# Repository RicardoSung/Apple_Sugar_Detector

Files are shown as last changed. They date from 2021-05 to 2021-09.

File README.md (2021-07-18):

# Apple Sugar Detector
> Apple sugar detector is a complete set of the construction of DIYed brix hydrometer targeted on Apples.

## Installation

* Prerequisites:
   *  Autodesk Inventor 2020 +
   *  Cadence OrCAD Alllegro 17.4 +
   *  Xilinx ISE Designer 14.7 +
   *  Python 3.8 
   *  Tensorflow 2.5.0   
   *  [usb-serial-for-android](https://github.com/mik3y/usb-serial-for-android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,are%20required%3B%20all%20drivers%20are%20implemented%20in%20Java.) library

For installable APK, please direct to `release`.

## Usage example

TBD

## Release History

### 0.x Internal Version

* 0.0.1
    * Work in progress, framework uploaded
* 0.1
    * PCB design first version uploaded
    * External structure first version uploaded
    * Android application first version uploaded
* 0.2
    * PCB design second version uploaded
    * External structure second version uploaded
    * Android application second version uploaded
    * Optic simulation first version uploaded
* 0.3
    * Neural network first version uploaded
    * External structure third version uploaded
    * Optic simulation second version uploaded
* 0.4
    * Optic simulation third version uploaded
    * 3D printing first version
* 0.5
    * Optic simulation fourth version uploaded
    * 3D printing second version
    * First training dataset acquired 

## Meta

Distributed under the GPL license. See ``LICENSE`` for more information.

## Contributing

1. Fork it (<https://github.com/GeekerRicardo/fruit_companion/fork>)
2. Create your feature branch (`git checkout -b feature/fooBar`)
3. Commit your changes (`git commit -am 'Add some fooBar'`)
4. Push to the branch (`git push origin feature/fooBar`)
5. Create a new Pull Request

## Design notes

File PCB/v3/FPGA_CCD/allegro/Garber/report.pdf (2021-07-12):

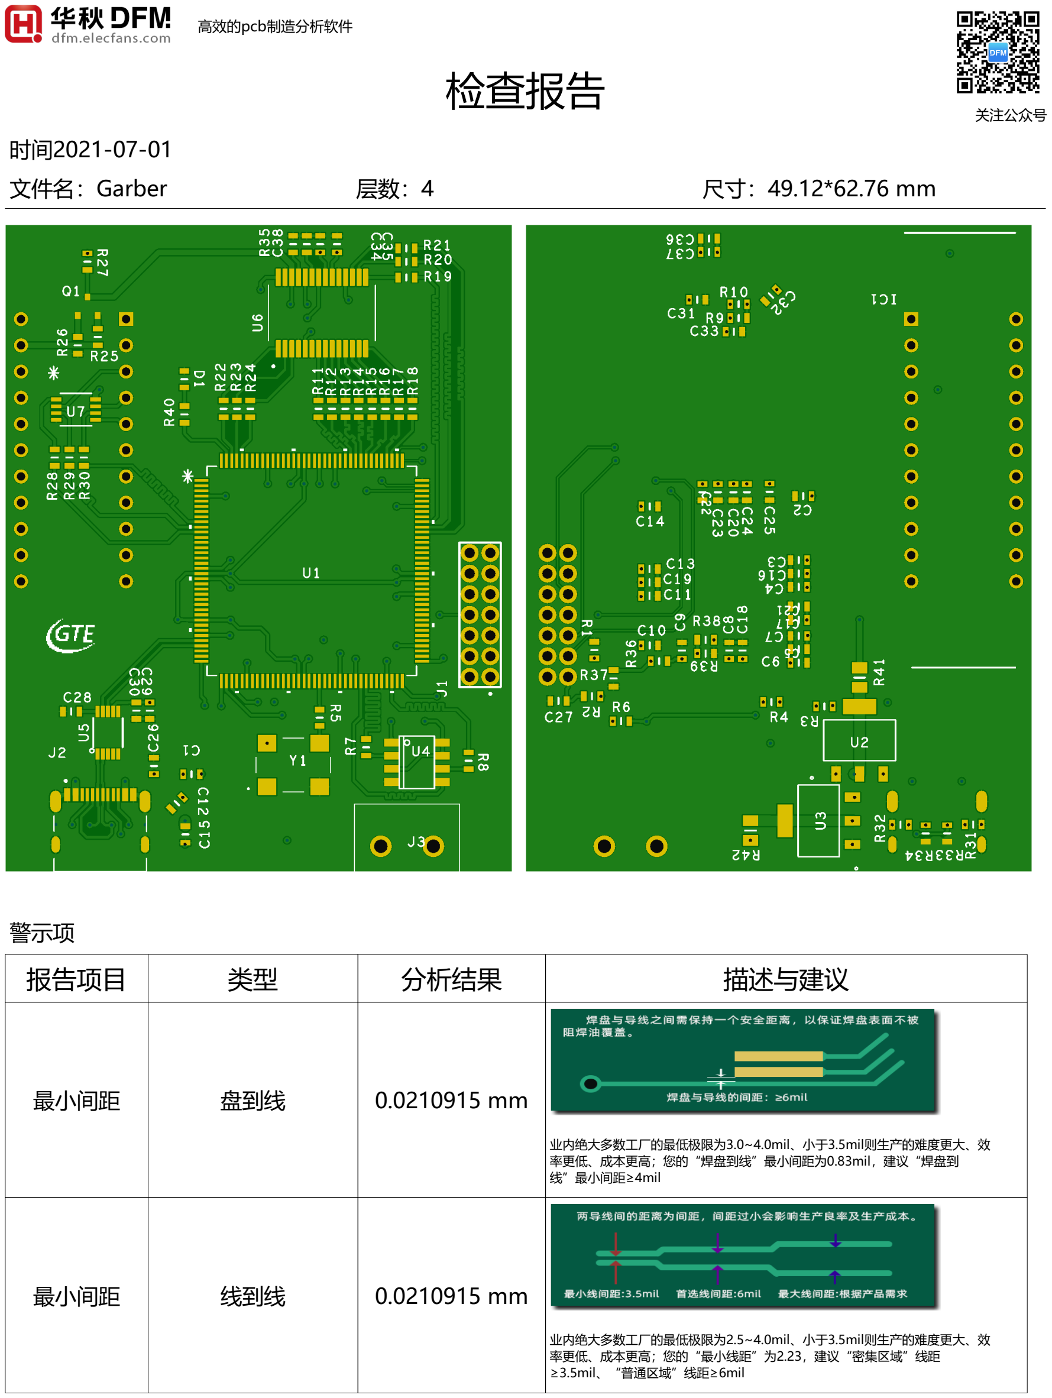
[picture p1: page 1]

高效的pcb制造分析软件

检查报告 | 关注公众号

时间2021-07-01

文件名：Garber | 层数：4 | 尺寸：49.12*62.76 mm

警示项
报告项目 | 类型 | 分析结果 | 描述与建议
最小间距 | 盘到线 | 0.0210915 mm | 业内绝大多数工厂的最低极限为3.0~4.0mil、小于3.5mil则生产的难度更大、效 率更低、成本更高；您的“焊盘到线”最小间距为0.83mil，建议“焊盘到 线”最小间距≥4mil
最小间距 | 线到线 | 0.0210915 mm | 业内绝大多数工厂的最低极限为2.5~4.0mil、小于3.5mil则生产的难度更大、效 率更低、成本更高；您的“最小线距”为2.23，建议“密集区域”线距 ≥3.5mil、“普通区域”线距≥6mil

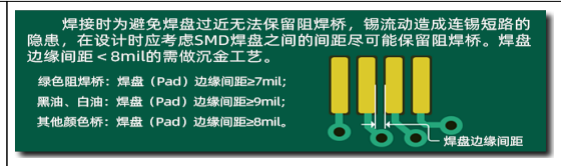
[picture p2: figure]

SMD间距 | 不同网络SMD焊盘间 距 | 0.169926 mm | 您的“SMD焊盘”最小间距为6.69mil会影响生产效率、品质良率，而且存在连 锡隐患，建议“SMD焊盘”最小间距 ≥ 8 mil

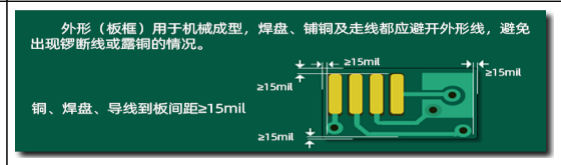
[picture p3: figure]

板边距离 | 铜/PAD/线到板边距 离 | 板边异常 | 业内绝大多数工厂的锣边极限为8mil，小于该极限值，有露铜甚至断线的隐患； 您的“导线/焊盘/覆铜到板边”最小间距为0.00mil，建议≥10mil；如是V割 边，建议≥15mil，具体极限值与板厚、V刀角度有关，规则请查看“DFM文 档”

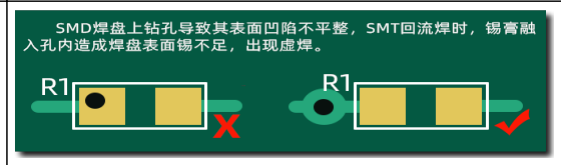
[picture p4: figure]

孔上焊盘 | 插件孔 | 有盘中孔 | 您的“设计”存在“孔在SMD焊盘上”，会影响焊盘的平整度，可能会导致焊 锡不良。

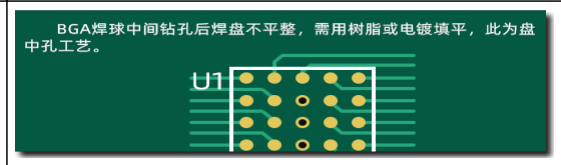
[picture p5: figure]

孔上焊盘 | 盘中孔 | 有盘中孔 | 您的“设计”可能存在“盘中孔”，如是BGA区域，须用树脂塞孔工艺，会导致 额外收费。

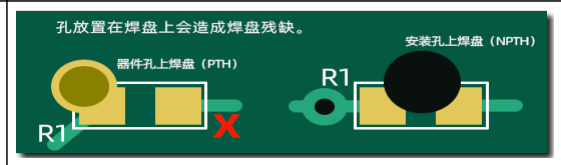
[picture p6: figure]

孔上焊盘 | 过孔上焊盘 | 有盘中孔 | 您的“设计”存在“孔在SMD焊盘上”，会影响焊盘的平整度，可能会导致焊 锡不良。

全部检查项
报告项目 | 类型 | 分析结果
电气信号 开短路 | 断头线 | 正常
| 孤立铜 | 正常
| 无效过孔 | 正常
| 片式SMD没连线路 | 正常
| 锐角 | 正常
最小线宽 | 最小线宽 | 正常 0.127 mm

最小间距 | 线到线 | 30pis 0.0210915 mm
| 盘到线 | 241pis 0.0210915 mm
| 盘到盘 | 正常 0.0210915 mm
最小焊盘 | BGA焊盘 | 正常
| 常规焊盘 | 正常
| 长条焊盘 | 正常
SMD间距 | 同网络SMD焊盘间距 | 正常
| 不同网络SMD焊盘间 距 | 175pis 0.169926 mm
| 同器件焊盘间距 | 正常
| 不同器件焊盘间距 | 正常
网格铺铜 | 网格线宽 | 正常
| 网格线距 | 正常
孔大小 | 最小孔径 | 正常 0.3302 mm
| 最大孔径 | 正常
| 厚径比 | 正常
槽孔 | 最小槽宽 | 正常
| 最大槽宽 | 正常
| 槽长宽比 | 正常
孔环 | 过孔孔环 | 正常
| 插件孔孔环 | 正常
孔到孔 | 同网络过孔 | 正常
| 不同网络过孔 | 正常
| 插件孔 | 1pis 有盘中孔

孔到线 | 过孔到表层 | 正常 0.2667 mm
| 插件孔到表层 | 正常 0.2667 mm
| 过孔到内层 | 正常
| 插件孔到内层 | 正常
| NPTH到铜 | 正常 0.2667 mm
板边距离 | 铜/PAD/线到板边距 离 | 16pis 板边异常
| SMD到板边距离 | 正常
| 孔到板边 | 正常
特殊孔 | 半孔 | 正常
| 盲埋孔 | 正常
| 盲埋孔距离 | 正常
| 激光孔 | 正常
| 正/长方形孔 | 正常
焊盘规格 | 焊盘大小异常 | 正常
| 分装内间距异常 | 正常
孔上焊盘 | 盘中孔 | 21pis 有盘中孔
| 插件孔 | 1pis 有盘中孔
| 过孔上焊盘 | 59pis 有盘中孔
| 非金属孔 | 正常
阻焊开窗 | 阻焊异常 | 正常
| 阻焊盖线 | 正常
| 阻焊间隙 | 正常
| 同网络阻焊间隙 | 正常
| 漏阻焊桥 | 正常
| 同网络漏阻焊桥 | 正常

孔密度 | 孔密度 | 正常
沉金面积 | 沉金面积 | 正常
飞针点数 | 飞针点数 | 正常

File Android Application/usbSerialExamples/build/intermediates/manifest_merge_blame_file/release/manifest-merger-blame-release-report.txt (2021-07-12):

1<?xml version="1.0" encoding="utf-8"?>
2<manifest xmlns:android="http://schemas.android.com/apk/res/android"
3    package="com.hoho.android.usbserial.examples" >
4
5    <uses-sdk
6        android:minSdkVersion="24"
6-->D:\Android\AndroidCode\usb-serial-for-android-master\usbSerialExamples\src\main\AndroidManifest.xml
7        android:targetSdkVersion="30" />
7-->D:\Android\AndroidCode\usb-serial-for-android-master\usbSerialExamples\src\main\AndroidManifest.xml
8    <!-- mipmap/ic_launcher created with Android Studio -> New -> Image Asset using @color/colorPrimary and USB clip art -->
9    <application
9-->D:\Android\AndroidCode\usb-serial-for-android-master\usbSerialExamples\src\main\AndroidManifest.xml:7:5-32:19
10        android:appComponentFactory="androidx.core.app.CoreComponentFactory"
10-->[androidx.core:core:1.3.1] C:\Users\Voluntino\.gradle\caches\transforms-3\2d8ae992b7b26928b91c87685f1e70d4\transformed\core-1.3.1\AndroidManifest.xml:24:18-86
11        android:extractNativeLibs="false"
12        android:icon="@mipmap/red_apple"
12-->D:\Android\AndroidCode\usb-serial-for-android-master\usbSerialExamples\src\main\AndroidManifest.xml:8:9-41
13        android:label="@string/app_name"
13-->D:\Android\AndroidCode\usb-serial-for-android-master\usbSerialExamples\src\main\AndroidManifest.xml:9:9-41
14        android:theme="@style/AppTheme" >
14-->D:\Android\AndroidCode\usb-serial-for-android-master\usbSerialExamples\src\main\AndroidManifest.xml:10:9-40
15
16        <!--
17             for this simple app launchMode=singleTask and singleTop have same effect.
18             If you would start another activity in the app, e.g. Android Settings
19             then you should use singleTask, else a new MainActivity would be started
20             when the settings activity is currently shown
21        -->
22        <activity
22-->D:\Android\AndroidCode\usb-serial-for-android-master\usbSerialExamples\src\main\AndroidManifest.xml:16:9-31:20
23            android:name="com.hoho.android.usbserial.examples.MainActivity"
23-->D:\Android\AndroidCode\usb-serial-for-android-master\usbSerialExamples\src\main\AndroidManifest.xml:17:13-41
24            android:label="@string/app_name"
24-->D:\Android\AndroidCode\usb-serial-for-android-master\usbSerialExamples\src\main\AndroidManifest.xml:18:13-45
25            android:launchMode="singleTask"
25-->D:\Android\AndroidCode\usb-serial-for-android-master\usbSerialExamples\src\main\AndroidManifest.xml:19:13-44
26            android:windowSoftInputMode="stateHidden|adjustResize" >
26-->D:\Android\AndroidCode\usb-serial-for-android-master\usbSerialExamples\src\main\AndroidManifest.xml:20:13-67
27            <intent-filter>
27-->D:\Android\AndroidCode\usb-serial-for-android-master\usbSerialExamples\src\main\AndroidManifest.xml:21:13-24:29
28                <action android:name="android.intent.action.MAIN" />
28-->D:\Android\AndroidCode\usb-serial-for-android-master\usbSerialExamples\src\main\AndroidManifest.xml:22:17-69
28-->D:\Android\AndroidCode\usb-serial-for-android-master\usbSerialExamples\src\main\AndroidManifest.xml:22:25-66
29
30                <category android:name="android.intent.category.LAUNCHER" />
30-->D:\Android\AndroidCode\usb-serial-for-android-master\usbSerialExamples\src\main\AndroidManifest.xml:23:17-77
30-->D:\Android\AndroidCode\usb-serial-for-android-master\usbSerialExamples\src\main\AndroidManifest.xml:23:27-74
31            </intent-filter>
32            <intent-filter>
32-->D:\Android\AndroidCode\usb-serial-for-android-master\usbSerialExamples\src\main\AndroidManifest.xml:25:13-27:29
33                <action android:name="android.hardware.usb.action.USB_DEVICE_ATTACHED" />
33-->D:\Android\AndroidCode\usb-serial-for-android-master\usbSerialExamples\src\main\AndroidManifest.xml:26:17-90
33-->D:\Android\AndroidCode\usb-serial-for-android-master\usbSerialExamples\src\main\AndroidManifest.xml:26:25-87
34            </intent-filter>
35
36            <meta-data
36-->D:\Android\AndroidCode\usb-serial-for-android-master\usbSerialExamples\src\main\AndroidManifest.xml:28:13-30:57
37                android:name="android.hardware.usb.action.USB_DEVICE_ATTACHED"
37-->D:\Android\AndroidCode\usb-serial-for-android-master\usbSerialExamples\src\main\AndroidManifest.xml:29:17-79
38                android:resource="@xml/device_filter" />
38-->D:\Android\AndroidCode\usb-serial-for-android-master\usbSerialExamples\src\main\AndroidManifest.xml:30:17-54
39        </activity>
40    </application>
41
42</manifest>

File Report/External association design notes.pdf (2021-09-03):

# 外部附件设计说明

# 学校：电子科技大学（UESTC）

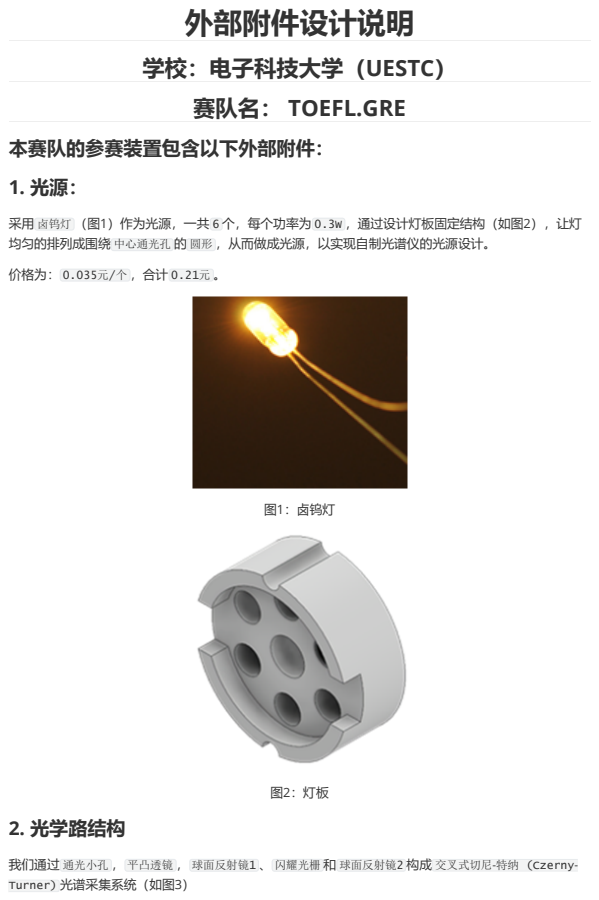
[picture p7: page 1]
本赛队的参赛装置包含以下外部附件：; 价格为： 0.035元/个 ，合计 0.21元 。; 图1：卤钨灯; 2. 光学路结构

赛队名： TOEFL.GRE

采用 卤钨灯 （图1）作为光源，一共 6 个，每个功率为 0.3W ，通过设计灯板固定结构（如图2），让灯
均匀的排列成围绕 中心通光孔 的 圆形 ，从而做成光源，以实现自制光谱仪的光源设计。

我们通过 通光小孔 ， 平凸透镜 ， 球面反射镜1 、 闪耀光栅 和 球面反射镜2 构成 交叉式切尼-特纳 (Czerny-
Turner) 光谱采集系统（如图3）

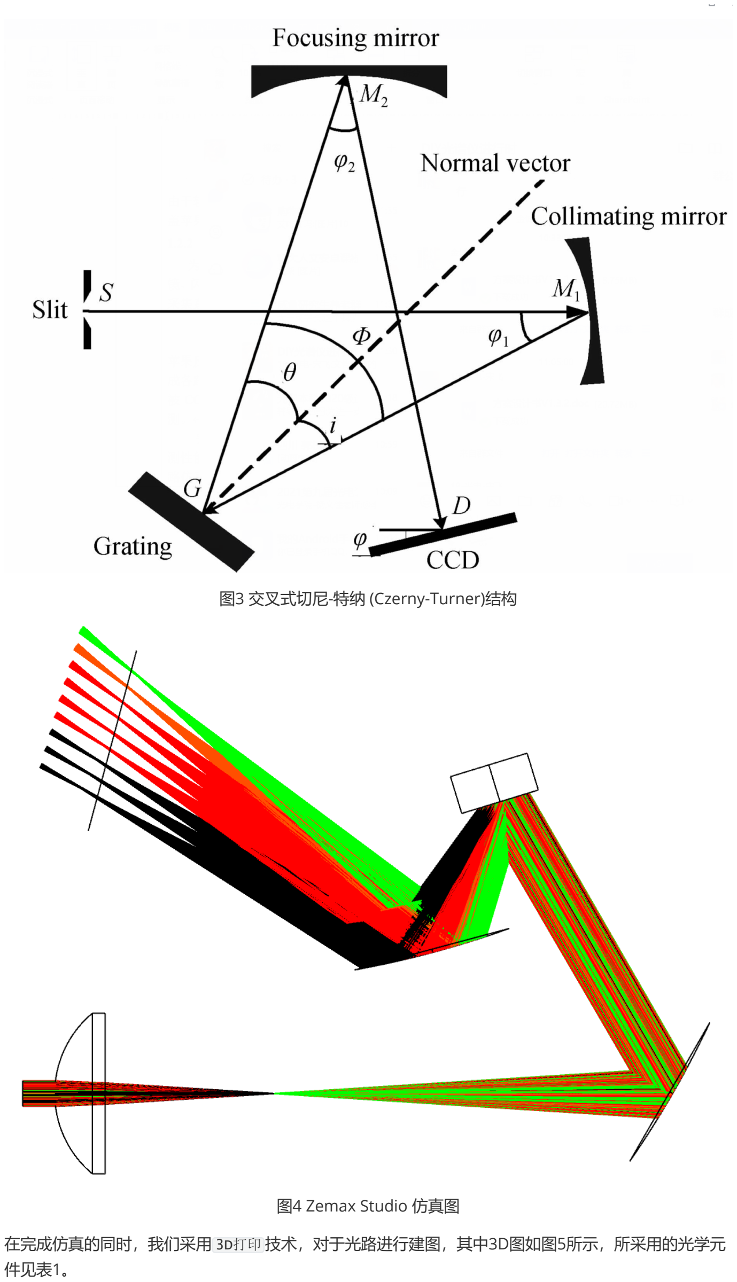
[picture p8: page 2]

图3 交叉式切尼-特纳 (Czerny-Turner)结构

图4 Zemax Studio 仿真图

在完成仿真的同时，我们采用 3D打印 技术，对于光路进行建图，其中3D图如图5所示，所采用的光学元 件见表1。

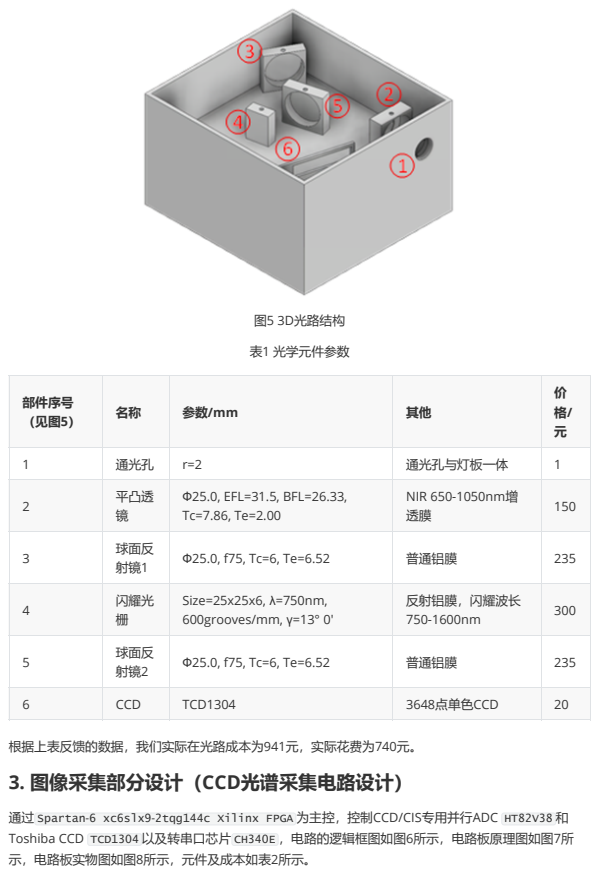
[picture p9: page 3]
图5 3D光路结构; 表1 光学元件参数; 根据上表反馈的数据，我们实际在光路成本为941元，实际花费为740元。 3. 图像采集部分设计（CCD光谱采集电路设计）

部件序号 （见图5） | 名称 | 参数/mm | 其他 | 价 格/ 元

1 | 通光孔 | r=2 | 通光孔与灯板一体 | 1

2 | 平凸透 镜 | Ф25.0, EFL=31.5, BFL=26.33, Tc=7.86, Te=2.00 | NIR 650-1050nm增 透膜 | 150

3 | 球面反 射镜1 | Ф25.0, f75, Tc=6, Te=6.52 | 普通铝膜 | 235

4 | 闪耀光 栅 | Size=25x25x6, λ=750nm, 600grooves/mm, γ=13° 0' | 反射铝膜，闪耀波长 750-1600nm | 300

5 | 球面反 射镜2 | Ф25.0, f75, Tc=6, Te=6.52 | 普通铝膜 | 235

6 | CCD | TCD1304 | 3648点单色CCD | 20

通过 Spartan-6 xc6slx9-2tqg144c Xilinx FPGA 为主控，控制CCD/CIS专用并行ADC HT82V38 和
Toshiba CCD TCD1304 以及转串口芯片 CH340E ，电路的逻辑框图如图6所示，电路板原理图如图7所
示，电路板实物图如图8所示，元件及成本如表2所示。

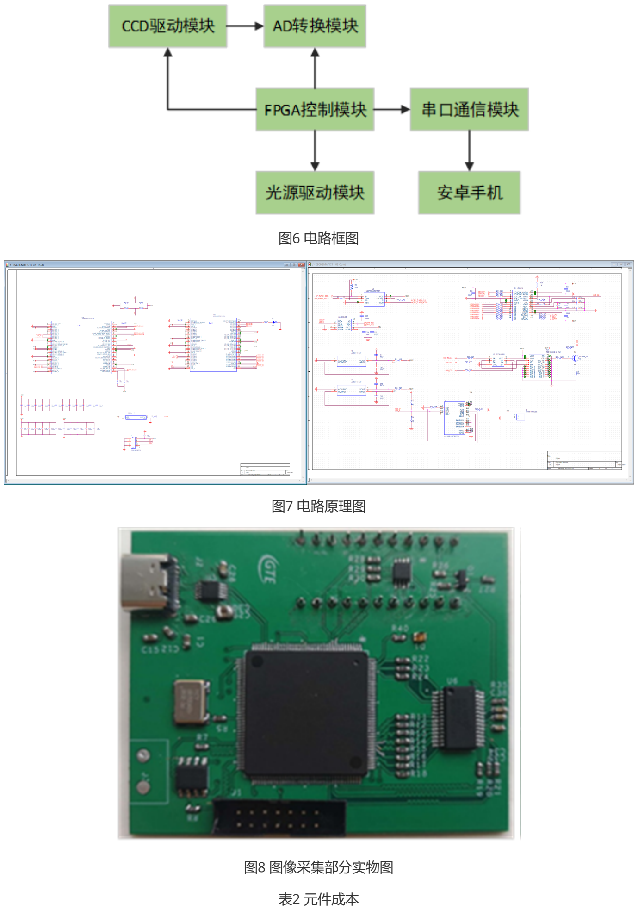
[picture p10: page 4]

图6 电路框图

图7 电路原理图

图8 图像采集部分实物图

表2 元件成本

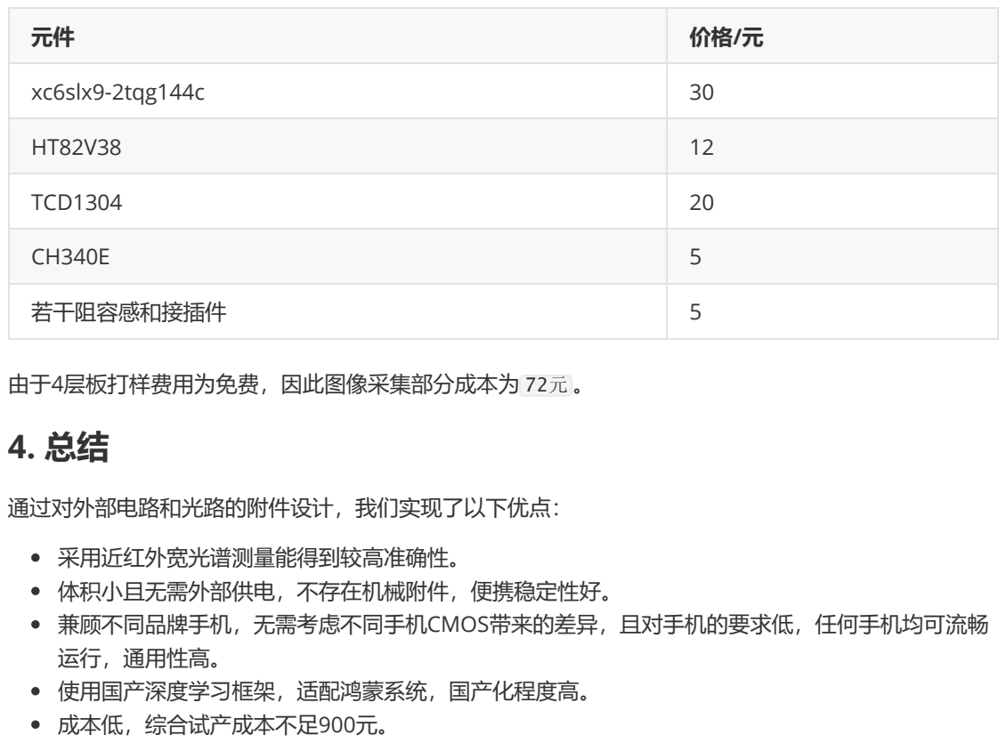
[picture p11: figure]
xc6slx9-2tqg144c; TCD1304; 若干阻容感和接插件; 由于4层板打样费用为免费，因此图像采集部分成本为 72元 。 4. 总结; 通过对外部电路和光路的附件设计，我们实现了以下优点：; 采用近红外宽光谱测量能得到较高准确性。 体积小且无需外部供电，不存在机械附件，便携稳定性好。 兼顾不同品牌手机，无需考虑不同手机CMOS带来的差异，且对手机的要求低，任何手机均可流畅 运行，通用性高。 使用国产深度学习框架，适配鸿蒙系统，国产化程度高。 成本低，综合试产成本不足900元。

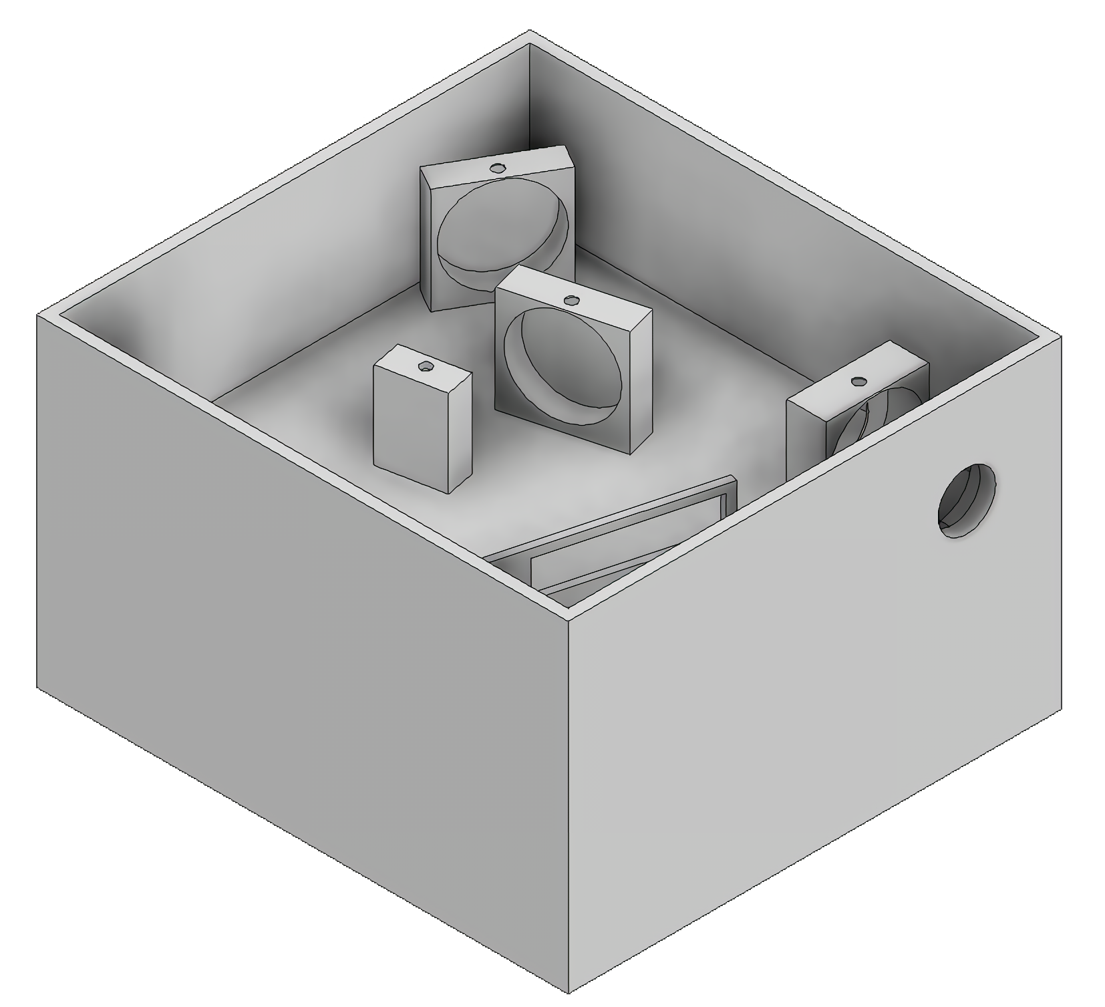
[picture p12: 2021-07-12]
Structure Design/box/box_waifu2x_art_noise3_scale_tta_1.png

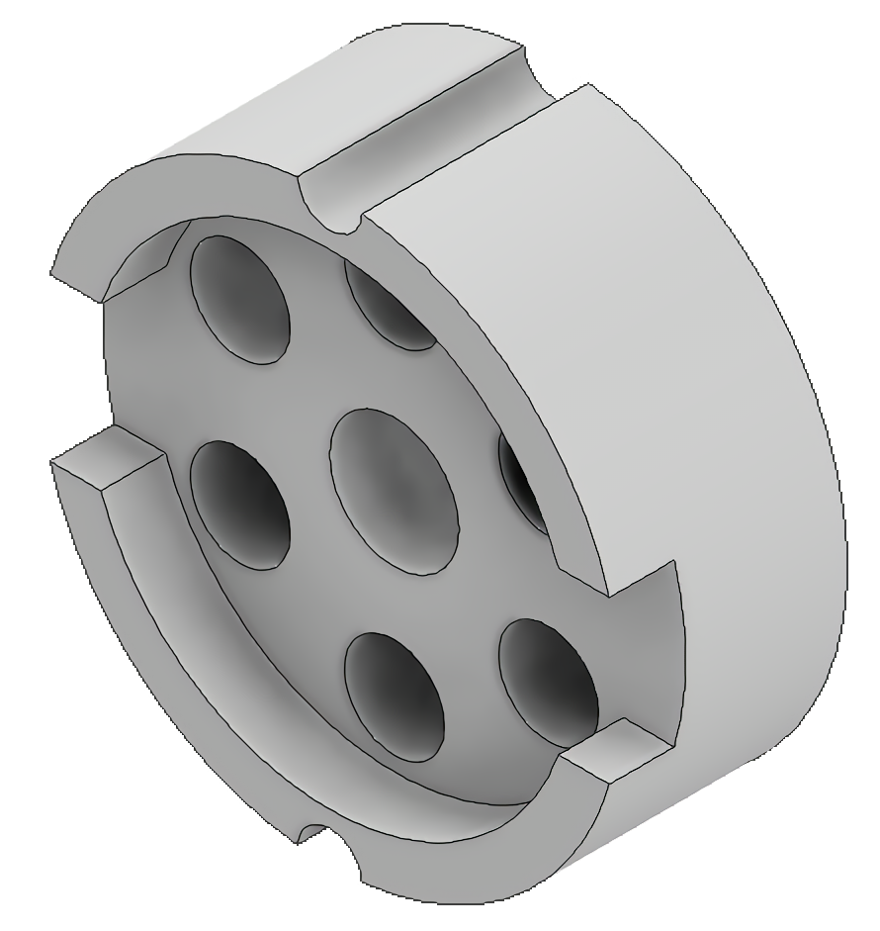
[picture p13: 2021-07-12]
Structure Design/hole/light_hole_waifu2x_art_noise3_scale_tta_1.png

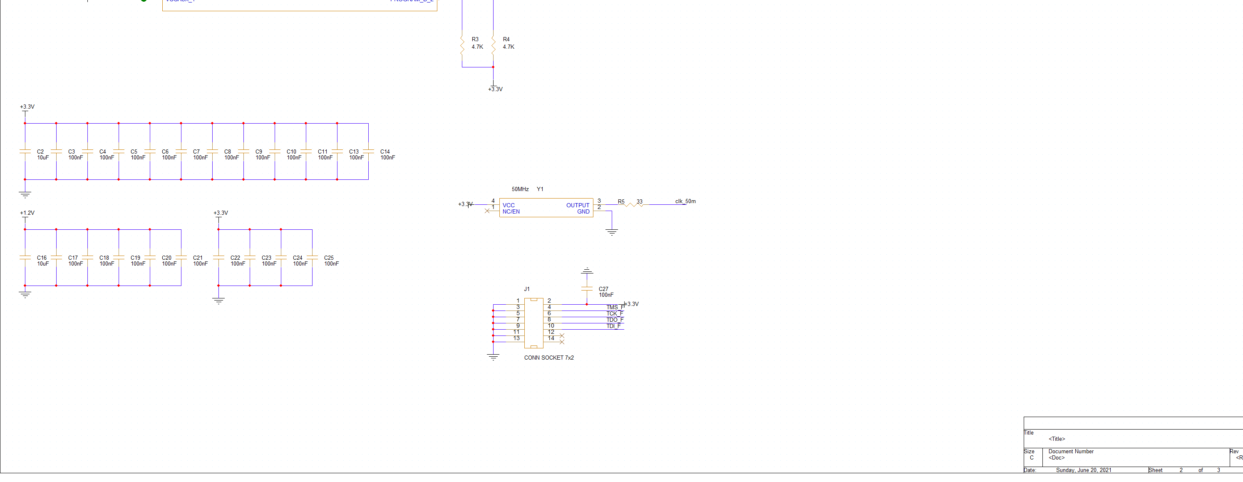
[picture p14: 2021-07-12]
PCB/v3/FPGA_CCD/FPGA_CCD.png

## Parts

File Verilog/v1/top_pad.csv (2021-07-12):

#Release 14.7 - par P.20131013 (nt)
#Copyright (c) 1995-2013 Xilinx | Inc. All rights reserved.
#Sun Jul 11 21:33:40 2021
#
## NOTE: This file is designed to be imported into a spreadsheet program
# such as Microsoft Excel for viewing | printing and sorting. The
# character is used as the data field separator. This file is also designed
# to support parsing.
#
#INPUT FILE: top_map.ncd
#OUTPUT FILE: top_pad.csv
#PART TYPE: xc6slx9
#SPEED GRADE: -3
#PACKAGE: tqg144
#
# Pinout by Pin Number:
#
# ----- | ----- | ----- | ----- | ----- | ----- | ----- | ----- | ----- | ----- | ----- | ----- | ----- | ----- | -----
Pin Number | Signal Name | Pin Usage | Pin Name | Direction | IO Standard | IO Bank Number | Drive (mA) | Slew Rate | Termination | IOB Delay | Voltage | Constraint | IO Register | Signal Integrity
P1 |  | IOBS | IO_L83N_VREF_3 | UNUSED |  | 3
P2 |  | IOBM | IO_L83P_3 | UNUSED |  | 3
P3 |  |  | GND
P4 |  |  | VCCO_3 |  |  | 3 |  |  |  |  | 3.30
P5 |  | IOBS | IO_L52N_3 | UNUSED |  | 3
P6 |  | IOBM | IO_L52P_3 | UNUSED |  | 3
P7 |  | IOBS | IO_L51N_3 | UNUSED |  | 3
P8 |  | IOBM | IO_L51P_3 | UNUSED |  | 3
P9 | CCD_ICG | IOB | IO_L50N_3 | OUTPUT | LVCMOS33 | 3 | 12 | SLOW |  |  |  | LOCATED | NO | NONE
P10 | CCD_SH | IOB | IO_L50P_3 | OUTPUT | LVCMOS33 | 3 | 12 | SLOW |  |  |  | LOCATED | NO | NONE
P11 | CCD_Master | IOB | IO_L49N_3 | OUTPUT | LVCMOS33 | 3 | 12 | SLOW |  |  |  | LOCATED | NO | NONE
P12 |  | IOBM | IO_L49P_3 | UNUSED |  | 3
P13 |  |  | GND
P14 |  | IOBS | IO_L44N_GCLK20_3 | UNUSED |  | 3
P15 |  | IOBM | IO_L44P_GCLK21_3 | UNUSED |  | 3
P16 |  | IOBS | IO_L43N_GCLK22_IRDY2_3 | UNUSED |  | 3
P17 |  | IOBM | IO_L43P_GCLK23_3 | UNUSED |  | 3
P18 |  |  | VCCO_3 |  |  | 3 |  |  |  |  | 3.30
P19 |  |  | VCCINT |  |  |  |  |  |  |  | 1.2
P20 |  |  | VCCAUX |  |  |  |  |  |  |  | 2.5
P21 |  | IOBS | IO_L42N_GCLK24_3 | UNUSED |  | 3
P22 |  | IOBM | IO_L42P_GCLK25_TRDY2_3 | UNUSED |  | 3
P23 |  | IOBS | IO_L41N_GCLK26_3 | UNUSED |  | 3
P24 |  | IOBM | IO_L41P_GCLK27_3 | UNUSED |  | 3
P25 |  |  | GND
P26 |  | IOBS | IO_L37N_3 | UNUSED |  | 3
P27 |  | IOBM | IO_L37P_3 | UNUSED |  | 3
P28 |  |  | VCCINT |  |  |  |  |  |  |  | 1.2
P29 |  | IOBS | IO_L36N_3 | UNUSED |  | 3
P30 |  | IOBM | IO_L36P_3 | UNUSED |  | 3
P31 |  |  | VCCO_3 |  |  | 3 |  |  |  |  | 3.30
P32 | UART_TXD | IOB | IO_L2N_3 | OUTPUT | LVCMOS33 | 3 | 12 | SLOW |  |  |  | LOCATED | NO | NONE
P33 | UART_RXD | IOB | IO_L2P_3 | INPUT | LVCMOS33 | 3 |  |  |  | NONE |  | LOCATED | NO | NONE
P34 |  | IOBS | IO_L1N_VREF_3 | UNUSED |  | 3
P35 |  | IOBM | IO_L1P_3 | UNUSED |  | 3
P36 |  |  | VCCAUX |  |  |  |  |  |  |  | 2.5
P37 |  |  | PROGRAM_B_2
P38 |  | IOBS | IO_L65N_CSO_B_2 | UNUSED |  | 2
P39 |  | IOBM | IO_L65P_INIT_B_2 | UNUSED |  | 2
P40 |  | IOBS | IO_L64N_D9_2 | UNUSED |  | 2
P41 |  | IOBM | IO_L64P_D8_2 | UNUSED |  | 2
P42 |  |  | VCCO_2 |  |  | 2 |  |  |  |  | any******
P43 |  | IOBS | IO_L62N_D6_2 | UNUSED |  | 2
P44 |  | IOBM | IO_L62P_D5_2 | UNUSED |  | 2
P45 |  | IOBS | IO_L49N_D4_2 | UNUSED |  | 2
P46 |  | IOBM | IO_L49P_D3_2 | UNUSED |  | 2
P47 |  | IOBS | IO_L48N_RDWR_B_VREF_2 | UNUSED |  | 2
P48 |  | IOBM | IO_L48P_D7_2 | UNUSED |  | 2
P49 |  |  | GND
P50 |  | IOBS | IO_L31N_GCLK30_D15_2 | UNUSED |  | 2
P51 |  | IOBM | IO_L31P_GCLK31_D14_2 | UNUSED |  | 2
P52 |  |  | VCCINT |  |  |  |  |  |  |  | 1.2
P53 |  |  | VCCAUX |  |  |  |  |  |  |  | 2.5
P54 |  |  | GND
P55 |  | IOBS | IO_L30N_GCLK0_USERCCLK_2 | UNUSED |  | 2
P56 | clk_50m | IOB | IO_L30P_GCLK1_D13_2 | INPUT | LVCMOS33 | 2 |  |  |  | NONE |  | LOCATED | NO | NONE
P57 |  | IOBS | IO_L14N_D12_2 | UNUSED |  | 2
P58 |  | IOBM | IO_L14P_D11_2 | UNUSED |  | 2
P59 |  | IOBS | IO_L13N_D10_2 | UNUSED |  | 2
P60 |  | IOBM | IO_L13P_M1_2 | UNUSED |  | 2
P61 |  | IOBS | IO_L12N_D2_MISO3_2 | UNUSED |  | 2
P62 |  | IOBM | IO_L12P_D1_MISO2_2 | UNUSED |  | 2
P63 |  |  | VCCO_2 |  |  | 2 |  |  |  |  | any******
P64 |  | IOBS | IO_L3N_MOSI_CSI_B_MISO0_2 | UNUSED |  | 2
P65 |  | IOBM | IO_L3P_D0_DIN_MISO_MISO1_2 | UNUSED |  | 2
P66 |  | IOBS | IO_L2N_CMPMOSI_2 | UNUSED |  | 2
P67 |  | IOBM | IO_L2P_CMPCLK_2 | UNUSED |  | 2
P68 |  |  | GND
P69 |  | IOBS | IO_L1N_M0_CMPMISO_2 | UNUSED |  | 2
P70 |  | IOBM | IO_L1P_CCLK_2 | UNUSED |  | 2
P71 |  |  | DONE_2
P72 |  |  | CMPCS_B_2
P73 |  |  | SUSPEND
P74 |  | IOBS | IO_L74N_DOUT_BUSY_1 | UNUSED |  | 1
P75 |  | IOBM | IO_L74P_AWAKE_1 | UNUSED |  | 1
P76 |  |  | VCCO_1 |  |  | 1 |  |  |  |  | any******
P77 |  |  | GND
P78 |  | IOBS | IO_L47N_1 | UNUSED |  | 1
P79 |  | IOBM | IO_L47P_1 | UNUSED |  | 1
P80 |  | IOBS | IO_L46N_1 | UNUSED |  | 1
P81 |  | IOBM | IO_L46P_1 | UNUSED |  | 1
P82 |  | IOBS | IO_L45N_1 | UNUSED |  | 1
P83 |  | IOBM | IO_L45P_1 | UNUSED |  | 1
P84 |  | IOBS | IO_L43N_GCLK4_1 | UNUSED |  | 1
P85 |  | IOBM | IO_L43P_GCLK5_1 | UNUSED |  | 1
P86 |  |  | VCCO_1 |  |  | 1 |  |  |  |  | any******
P87 |  | IOBS | IO_L42N_GCLK6_TRDY1_1 | UNUSED |  | 1
P88 |  | IOBM | IO_L42P_GCLK7_1 | UNUSED |  | 1
P89 |  |  | VCCINT |  |  |  |  |  |  |  | 1.2
P90 |  |  | VCCAUX |  |  |  |  |  |  |  | 2.5
P91 |  |  | GND
P92 |  | IOBS | IO_L41N_GCLK8_1 | UNUSED |  | 1
P93 |  | IOBM | IO_L41P_GCLK9_IRDY1_1 | UNUSED |  | 1
P94 |  | IOBS | IO_L40N_GCLK10_1 | UNUSED |  | 1
P95 |  | IOBM | IO_L40P_GCLK11_1 | UNUSED |  | 1
P96 |  |  | GND
P97 |  | IOBS | IO_L34N_1 | UNUSED |  | 1
P98 |  | IOBM | IO_L34P_1 | UNUSED |  | 1
P99 |  | IOBS | IO_L33N_1 | UNUSED |  | 1
P100 |  | IOBM | IO_L33P_1 | UNUSED |  | 1
P101 |  | IOBS | IO_L32N_1 | UNUSED |  | 1
P102 |  | IOBM | IO_L32P_1 | UNUSED |  | 1
P103 |  |  | VCCO_1 |  |  | 1 |  |  |  |  | any******
P104 |  | IOBS | IO_L1N_VREF_1 | UNUSED |  | 1
P105 |  | IOBM | IO_L1P_1 | UNUSED |  | 1
P106 |  |  | TDO
P107 |  |  | TMS
P108 |  |  | GND
P109 |  |  | TCK
P110 |  |  | TDI
P111 |  | IOBS | IO_L66N_SCP0_0 | UNUSED |  | 0
P112 |  | IOBM | IO_L66P_SCP1_0 | UNUSED |  | 0
P113 |  |  | GND
P114 |  | IOBS | IO_L65N_SCP2_0 | UNUSED |  | 0
P115 |  | IOBM | IO_L65P_SCP3_0 | UNUSED |  | 0
P116 |  | IOBS | IO_L64N_SCP4_0 | UNUSED |  | 0
P117 |  | IOBM | IO_L64P_SCP5_0 | UNUSED |  | 0
P118 |  | IOBS | IO_L63N_SCP6_0 | UNUSED |  | 0
P119 |  | IOBM | IO_L63P_SCP7_0 | UNUSED |  | 0
P120 |  | IOBS | IO_L62N_VREF_0 | UNUSED |  | 0
P121 |  | IOBM | IO_L62P_0 | UNUSED |  | 0
P122 |  |  | VCCO_0 |  |  | 0 |  |  |  |  | 3.30
P123 |  | IOBS | IO_L37N_GCLK12_0 | UNUSED |  | 0
P124 |  | IOBM | IO_L37P_GCLK13_0 | UNUSED |  | 0
P125 |  |  | VCCO_0 |  |  | 0 |  |  |  |  | 3.30
P126 |  | IOBS | IO_L36N_GCLK14_0 | UNUSED |  | 0
P127 |  | IOBM | IO_L36P_GCLK15_0 | UNUSED |  | 0
P128 |  |  | VCCINT |  |  |  |  |  |  |  | 1.2
P129 |  |  | VCCAUX |  |  |  |  |  |  |  | 2.5
P130 |  |  | GND
P131 |  | IOBS | IO_L35N_GCLK16_0 | UNUSED |  | 0
P132 |  | IOBM | IO_L35P_GCLK17_0 | UNUSED |  | 0
P133 |  | IOBS | IO_L34N_GCLK18_0 | UNUSED |  | 0
P134 |  | IOBM | IO_L34P_GCLK19_0 | UNUSED |  | 0
P135 |  |  | VCCO_0 |  |  | 0 |  |  |  |  | 3.30
P136 |  |  | GND
P137 |  | IOBS | IO_L4N_0 | UNUSED |  | 0
P138 |  | IOBM | IO_L4P_0 | UNUSED |  | 0
P139 |  | IOBS | IO_L3N_0 | UNUSED |  | 0
P140 |  | IOBM | IO_L3P_0 | UNUSED |  | 0
P141 |  | IOBS | IO_L2N_0 | UNUSED |  | 0
P142 |  | IOBM | IO_L2P_0 | UNUSED |  | 0
P143 | led | IOB | IO_L1N_VREF_0 | OUTPUT | LVCMOS33 | 0 | 12 | SLOW |  |  |  | LOCATED | YES | NONE
P144 |  | IOBM | IO_L1P_HSWAPEN_0 | UNUSED |  | 0
# ----- | ----- | ----- | ----- | ----- | ----- | ----- | ----- | ----- | ----- | ----- | ----- | ----- | ----- | -----
#
#* Default value.
#** This default Pullup/Pulldown value can be overridden in Bitgen.
#****** Special VCCO requirements may apply. Please consult the device
# family datasheet for specific guideline on VCCO requirements.
#
#
#

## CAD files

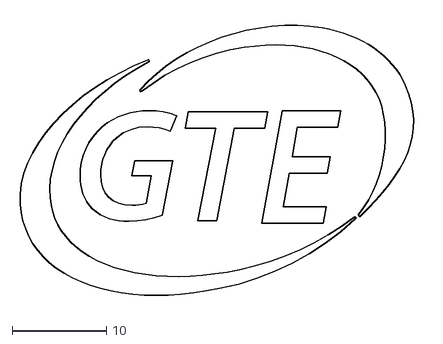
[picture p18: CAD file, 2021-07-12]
PCB/v3/FPGA_CCD/allegro/logo.dxf
43.7 x 30.5

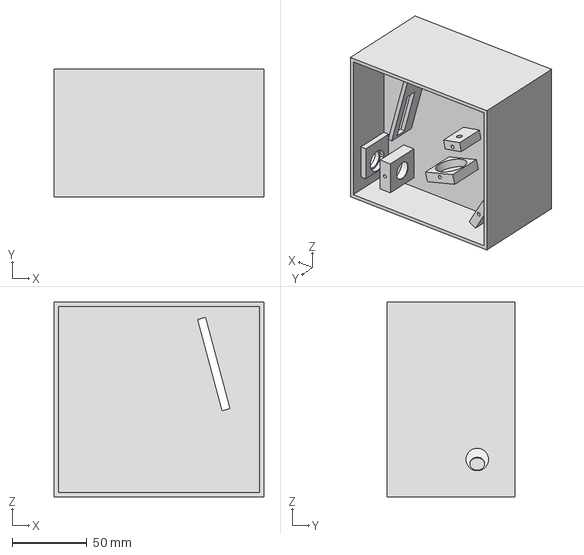
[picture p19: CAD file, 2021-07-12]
Structure Design/box/box.stp
140.0 x 85.0 x 130.0 mm

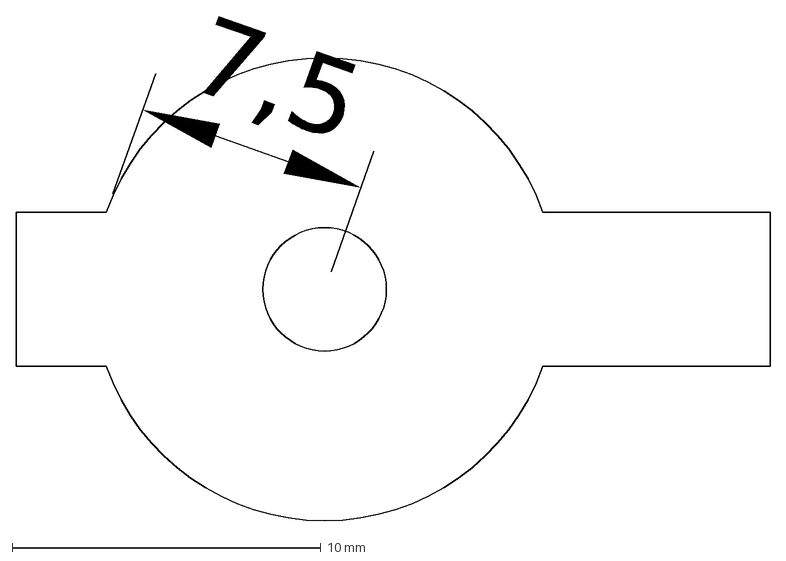
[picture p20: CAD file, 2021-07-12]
Structure Design/hole/light.dxf
7,5

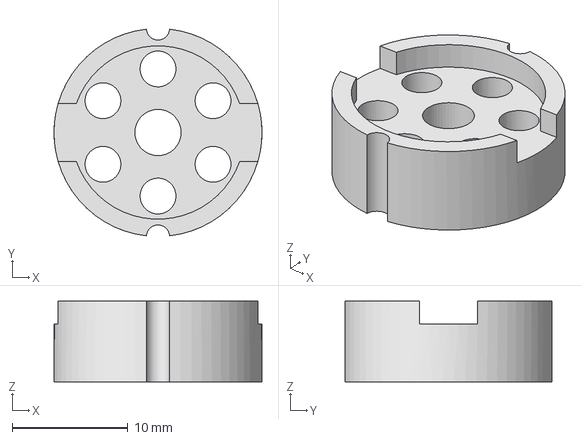
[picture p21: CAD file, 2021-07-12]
Structure Design/hole/light_hole.stp
18.0 x 17.9 x 7.00 mm

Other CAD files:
Verilog/v1/isim/HT_Serial_Interface_isim_beh.exe.sim/work/HT_Serial_Interface_isim_beh.exe_main.nt64.obj
Structure Design/hole/Light18.dxf
Verilog/v1/isim/HT_Serial_Interface_isim_beh.exe.sim/work/m_00000000002805513228_0080468737.nt64.obj
Verilog/v1/isim/HT_Serial_Interface_isim_beh.exe.sim/work/m_00000000004134447467_2073120511.nt64.obj
Verilog/v1/isim/HT_Serial_Interface_isim_beh.exe.sim/work/m_00000000001677316810_1873480705.nt64.obj
Structure Design/box/box.ipt
Structure Design/box/box.obj
Structure Design/hole/light.dwg
Structure Design/hole/light_hole.igs
Structure Design/hole/light_hole.ipt
Structure Design/hole/light_hole.obj
Structure Design/hole/light_hole.stl
Structure Design/lid/lid.ipt

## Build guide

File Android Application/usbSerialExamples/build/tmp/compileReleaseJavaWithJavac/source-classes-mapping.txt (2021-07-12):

com/hoho/android/usbserial/examples/CustomProber.java
 com.hoho.android.usbserial.examples.CustomProber
com/hoho/android/usbserial/examples/BuildConfig.java
 com.hoho.android.usbserial.examples.BuildConfig
com/hoho/android/usbserial/examples/MainActivity.java
 com.hoho.android.usbserial.examples.MainActivity
com/hoho/android/usbserial/examples/TFLiteLoader.java
 com.hoho.android.usbserial.examples.TFLiteLoader
com/hoho/android/usbserial/examples/ChartUtil.java
 com.hoho.android.usbserial.examples.ChartUtil
 com.hoho.android.usbserial.examples.CustomMarkerView
com/hoho/android/usbserial/util/HexDump.java
 com.hoho.android.usbserial.util.HexDump
com/hoho/android/usbserial/examples/DevicesFragment.java
 com.hoho.android.usbserial.examples.DevicesFragment
 com.hoho.android.usbserial.examples.DevicesFragment$1
 com.hoho.android.usbserial.examples.DevicesFragment$ListItem
com/hoho/android/usbserial/examples/TerminalFragment.java
 com.hoho.android.usbserial.examples.TerminalFragment
 com.hoho.android.usbserial.examples.TerminalFragment$1
 com.hoho.android.usbserial.examples.TerminalFragment$ControlLines
 com.hoho.android.usbserial.examples.TerminalFragment$UsbPermission

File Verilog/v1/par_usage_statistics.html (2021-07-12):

Par Statistics

Total Non-vccgnd Signals=273

Total Non-vccgnd Design Pins=749

Total Non-vccgnd Conns=749

Total Non-vccgnd Timing Constrained Conns=725

Phase 1 CPU=2.2 sec

Phase 2 CPU=2.3 sec

Phase 3 CPU=2.5 sec

Phase 4 CPU=2.7 sec

Phase 5 CPU=2.8 sec

Phase 6 CPU=2.8 sec

Phase 7 CPU=2.8 sec

Phase 8 CPU=2.8 sec

Phase 9 CPU=2.8 sec

Phase 10 CPU=2.8 sec

AvgWirelenPerPin Fanout 1=1.0

AvgWirelenPerPin Fanout 2=1.5

AvgWirelenPerPin Fanout 3=1.7

AvgWirelenPerPin Fanout 4=1.8

AvgWirelenPerPin Fanout 10=2.8

AvgWirelenPerPin Fanout 50=2.5

AvgWirelenPerPin Fanout 100=0.0

AvgWirelenPerPin Fanout 500=0.0

AvgWirelenPerPin Fanout 5000=0.0

AvgWirelenPerPin Fanout 20000=0.0

AvgWirelenPerPin Fanout 50000=0.0

AvgWirelenPerPin Fanout 100000=0.0

IRR Gamma=1.0954

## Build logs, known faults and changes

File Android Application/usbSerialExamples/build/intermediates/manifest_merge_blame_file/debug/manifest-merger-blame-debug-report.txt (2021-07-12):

1<?xml version="1.0" encoding="utf-8"?>
2<manifest xmlns:android="http://schemas.android.com/apk/res/android"
3    package="com.hoho.android.usbserial.examples" >
4
5    <uses-sdk
6        android:minSdkVersion="24"
6-->D:\Android\AndroidCode\usb-serial-for-android-master\usbSerialExamples\src\main\AndroidManifest.xml
7        android:targetSdkVersion="30" />
7-->D:\Android\AndroidCode\usb-serial-for-android-master\usbSerialExamples\src\main\AndroidManifest.xml
8    <!-- mipmap/ic_launcher created with Android Studio -> New -> Image Asset using @color/colorPrimary and USB clip art -->
9    <application
9-->D:\Android\AndroidCode\usb-serial-for-android-master\usbSerialExamples\src\main\AndroidManifest.xml:7:5-32:19
10        android:appComponentFactory="androidx.core.app.CoreComponentFactory"
10-->[androidx.core:core:1.3.1] C:\Users\Voluntino\.gradle\caches\transforms-3\2d8ae992b7b26928b91c87685f1e70d4\transformed\core-1.3.1\AndroidManifest.xml:24:18-86
11        android:debuggable="true"
12        android:extractNativeLibs="false"
13        android:icon="@mipmap/red_apple"
13-->D:\Android\AndroidCode\usb-serial-for-android-master\usbSerialExamples\src\main\AndroidManifest.xml:8:9-41
14        android:label="@string/app_name"
14-->D:\Android\AndroidCode\usb-serial-for-android-master\usbSerialExamples\src\main\AndroidManifest.xml:9:9-41
15        android:testOnly="true"
16        android:theme="@style/AppTheme" >
16-->D:\Android\AndroidCode\usb-serial-for-android-master\usbSerialExamples\src\main\AndroidManifest.xml:10:9-40
17
18        <!--
19             for this simple app launchMode=singleTask and singleTop have same effect.
20             If you would start another activity in the app, e.g. Android Settings
21             then you should use singleTask, else a new MainActivity would be started
22             when the settings activity is currently shown
23        -->
24        <activity
24-->D:\Android\AndroidCode\usb-serial-for-android-master\usbSerialExamples\src\main\AndroidManifest.xml:16:9-31:20
25            android:name="com.hoho.android.usbserial.examples.MainActivity"
25-->D:\Android\AndroidCode\usb-serial-for-android-master\usbSerialExamples\src\main\AndroidManifest.xml:17:13-41
26            android:label="@string/app_name"
26-->D:\Android\AndroidCode\usb-serial-for-android-master\usbSerialExamples\src\main\AndroidManifest.xml:18:13-45
27            android:launchMode="singleTask"
27-->D:\Android\AndroidCode\usb-serial-for-android-master\usbSerialExamples\src\main\AndroidManifest.xml:19:13-44
28            android:windowSoftInputMode="stateHidden|adjustResize" >
28-->D:\Android\AndroidCode\usb-serial-for-android-master\usbSerialExamples\src\main\AndroidManifest.xml:20:13-67
29            <intent-filter>
29-->D:\Android\AndroidCode\usb-serial-for-android-master\usbSerialExamples\src\main\AndroidManifest.xml:21:13-24:29
30                <action android:name="android.intent.action.MAIN" />
30-->D:\Android\AndroidCode\usb-serial-for-android-master\usbSerialExamples\src\main\AndroidManifest.xml:22:17-69
30-->D:\Android\AndroidCode\usb-serial-for-android-master\usbSerialExamples\src\main\AndroidManifest.xml:22:25-66
31
32                <category android:name="android.intent.category.LAUNCHER" />
32-->D:\Android\AndroidCode\usb-serial-for-android-master\usbSerialExamples\src\main\AndroidManifest.xml:23:17-77
32-->D:\Android\AndroidCode\usb-serial-for-android-master\usbSerialExamples\src\main\AndroidManifest.xml:23:27-74
33            </intent-filter>
34            <intent-filter>
34-->D:\Android\AndroidCode\usb-serial-for-android-master\usbSerialExamples\src\main\AndroidManifest.xml:25:13-27:29
35                <action android:name="android.hardware.usb.action.USB_DEVICE_ATTACHED" />
35-->D:\Android\AndroidCode\usb-serial-for-android-master\usbSerialExamples\src\main\AndroidManifest.xml:26:17-90
35-->D:\Android\AndroidCode\usb-serial-for-android-master\usbSerialExamples\src\main\AndroidManifest.xml:26:25-87
36            </intent-filter>
37
38            <meta-data
38-->D:\Android\AndroidCode\usb-serial-for-android-master\usbSerialExamples\src\main\AndroidManifest.xml:28:13-30:57
39                android:name="android.hardware.usb.action.USB_DEVICE_ATTACHED"
39-->D:\Android\AndroidCode\usb-serial-for-android-master\usbSerialExamples\src\main\AndroidManifest.xml:29:17-79
40                android:resource="@xml/device_filter" />
40-->D:\Android\AndroidCode\usb-serial-for-android-master\usbSerialExamples\src\main\AndroidManifest.xml:30:17-54
41        </activity>
42    </application>
43
44</manifest>

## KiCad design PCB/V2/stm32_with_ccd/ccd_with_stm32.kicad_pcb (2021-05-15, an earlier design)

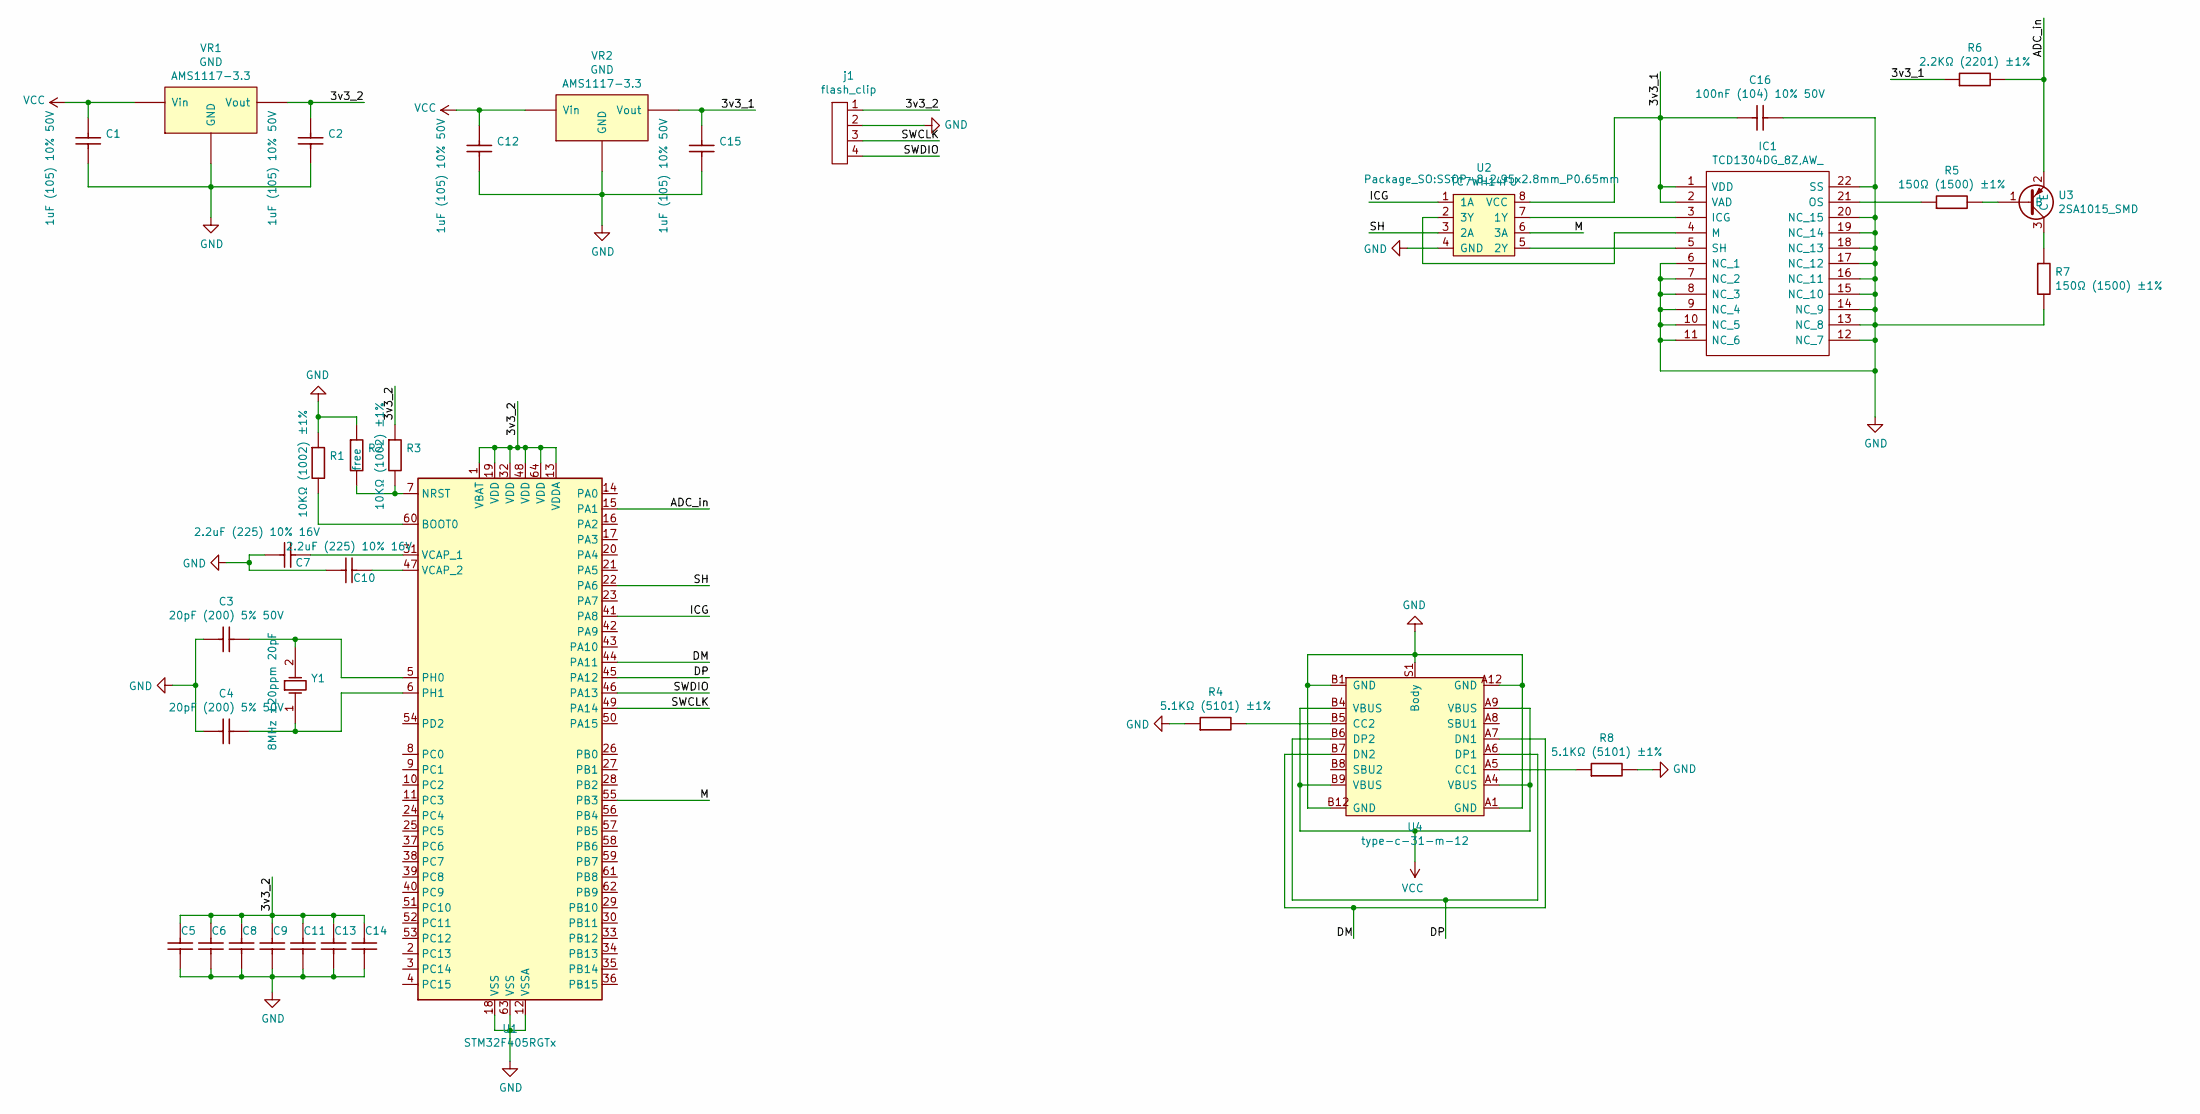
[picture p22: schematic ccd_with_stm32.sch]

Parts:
C1, C2, C12, C14, C15: 0603_1uF__105_10%_50V; 0603_C
C3, C4: 0603_20pF__200_5%_50V; 0603_C
C5, C6, C8, C9, C11, C13, C16: 0603_100nF__104_10%_50V; 0603_C
C7, C10: 0603_2.2uF__225_10%_16V; 0603_C
IC1: TCD1304DG_8Z,AW_; DIP1016W62P254L4160H372Q22N; Manufacturer_Part_Number TCD1304DG(8Z,AW); Mouser Part Number 757-TCD1304DG8ZAW
R1, R3: 0603_10KΩ__1002_1%; 0603_R
R2: 0402_1.2KΩ__1201_1%; 0402_R
R4, R8: 0603_5.1KΩ__5101_1%; 0603_R
R5, R7: 0603_150Ω__1500_1%; 0603_R
R6: 0603_2.2KΩ__2201_1%; 0603_R
U1: STM32F405RGTx; LQFP-64_10x10mm_P0.5mm
U2: TC7WH14FU; SSOP-8_2.95x2.8mm_P0.65mm
U3: 2SA1015_SMD; SOT-23(SOT-23-3)
U4: type-c-31-m-12; USB_C_Receptacle_HRO_TYPE-C-31-M-12
VR1, VR2: SOT-223_AMS1117-3.3; SOT-223
Y1: SMD-5032_2P_8MHz_20ppm_20pF; SMD-5032_2P
j1: flash_clip

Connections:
/3v3_1: C15.1, C16.1, IC1.1 (VDD), IC1.2 (VAD), R6.1, U2.8 (VCC), VR2.2 (Vout)
/3v3_2: C2.1, C5.1, C6.1, C8.1, C9.1, C11.1, C13.1, C14.1, R3.1, U1.1 (VBAT), U1.13 (VDDA), U1.19 (VDD), U1.32 (VDD), U1.48 (VDD), U1.64 (VDD), VR1.2 (Vout), j1.1
/ADC_in: R6.2, U1.15 (PA1), U3.2 (E)
/DM: U1.44 (PA11), U4.A7 (DN1), U4.B7 (DN2)
/DP: U1.45 (PA12), U4.A6 (DP1), U4.B6 (DP2)
/ICG: U1.41 (PA8), U2.1 (1A)
/M: U1.55 (PB3), U2.6 (3A)
/SH: U1.22 (PA6), U2.3 (2A)
/SWCLK: U1.49 (PA14), j1.3
/SWDIO: U1.46 (PA13), j1.4
GND: C1.2, C2.2, C3.1, C4.1, C5.2, C6.2, C7.1, C8.2, C9.2, C10.1, C11.2, C12.2, C13.2, C14.2, C15.2, C16.2, IC1.6 (NC_1), IC1.7 (NC_2), IC1.8 (NC_3), IC1.9 (NC_4), IC1.10 (NC_5), IC1.11 (NC_6), IC1.12 (NC_7), IC1.13 (NC_8), IC1.14 (NC_9), IC1.15 (NC_10), IC1.16 (NC_11), IC1.17 (NC_12), IC1.18 (NC_13), IC1.19 (NC_14), IC1.20 (NC_15), IC1.22 (SS), R1.1, R2.1, R4.1, R7.2, R8.2, U1.12 (VSSA), U1.18 (VSS), U1.63 (VSS), U2.4 (GND), U4.A1 (GND), U4.A12 (GND), U4.B1 (GND), U4.B12 (GND), U4.S1 (Body), VR1.1 (GND), VR2.1 (GND), j1.2
unnamed: C3.2, U1.5 (PH0), Y1.2 (OSC2)
unnamed: C4.2, U1.6 (PH1), Y1.1 (OSC1)
unnamed: C7.2, U1.31 (VCAP_1)
unnamed: C10.2, U1.47 (VCAP_2)
unnamed: IC1.3 (ICG), U2.7 (1Y)
unnamed: IC1.4 (M), U2.2 (3Y)
unnamed: IC1.5 (SH), U2.5 (2Y)
unnamed: IC1.21 (OS), R5.1
unnamed: R1.2, U1.60 (BOOT0)
unnamed: R2.2, R3.2, U1.7 (NRST)
unnamed: R4.2, U4.B5 (CC2)
unnamed: R5.2, U3.1 (B)
unnamed: R7.1, U3.3 (C)
unnamed: R8.1, U4.A5 (CC1)
VCC: C1.1, C12.1, U4.A4 (VBUS), U4.A9 (VBUS), U4.B4 (VBUS), U4.B9 (VBUS), VR1.3 (Vin), VR2.3 (Vin)

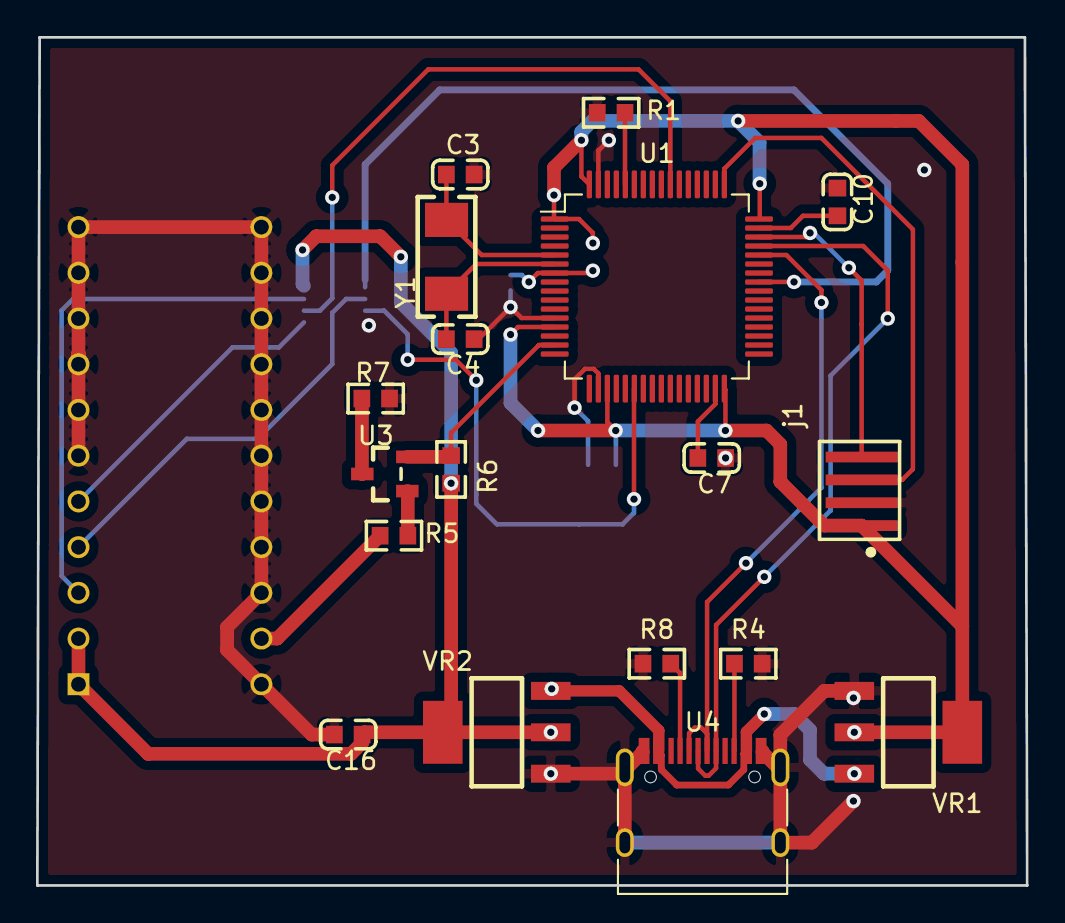
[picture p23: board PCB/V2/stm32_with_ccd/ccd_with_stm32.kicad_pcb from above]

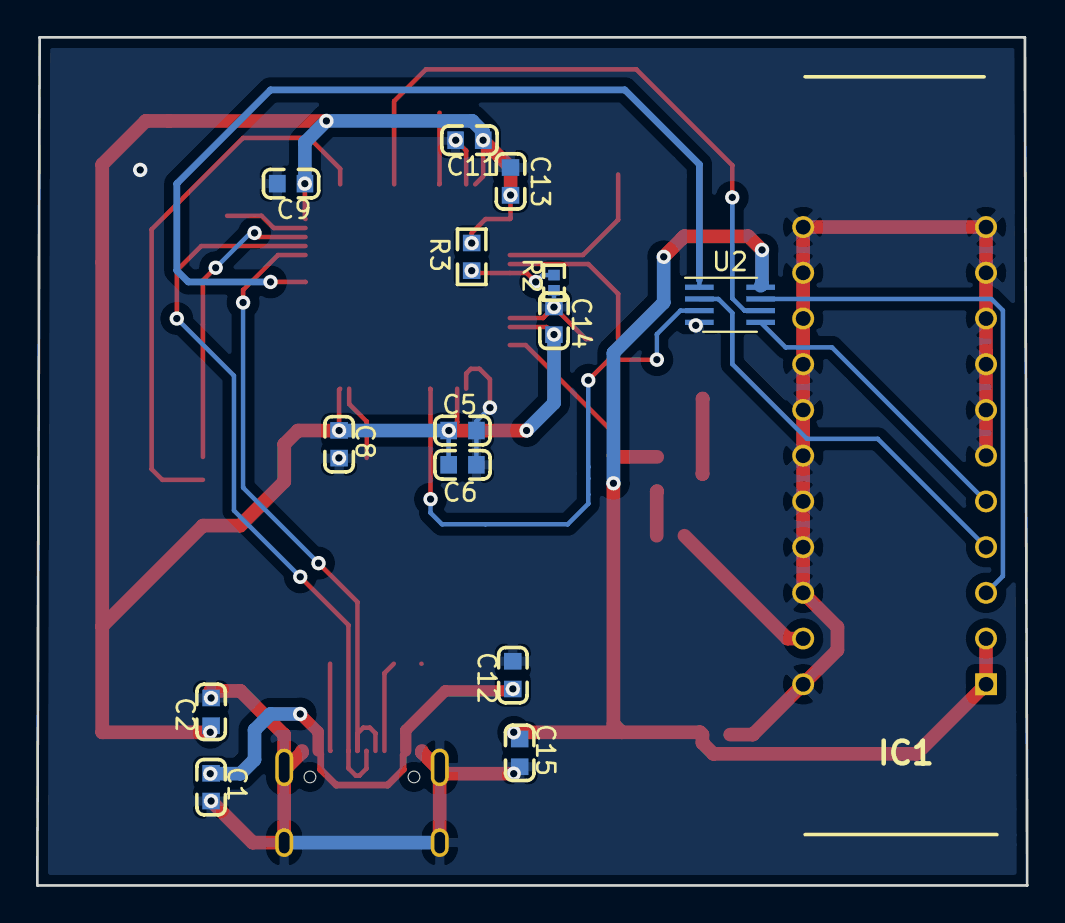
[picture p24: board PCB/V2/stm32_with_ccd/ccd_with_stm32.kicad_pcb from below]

Board: 2 copper layers, 55.0 x 47.1 mm, 33 parts (15 on the bottom side), 26 nets.

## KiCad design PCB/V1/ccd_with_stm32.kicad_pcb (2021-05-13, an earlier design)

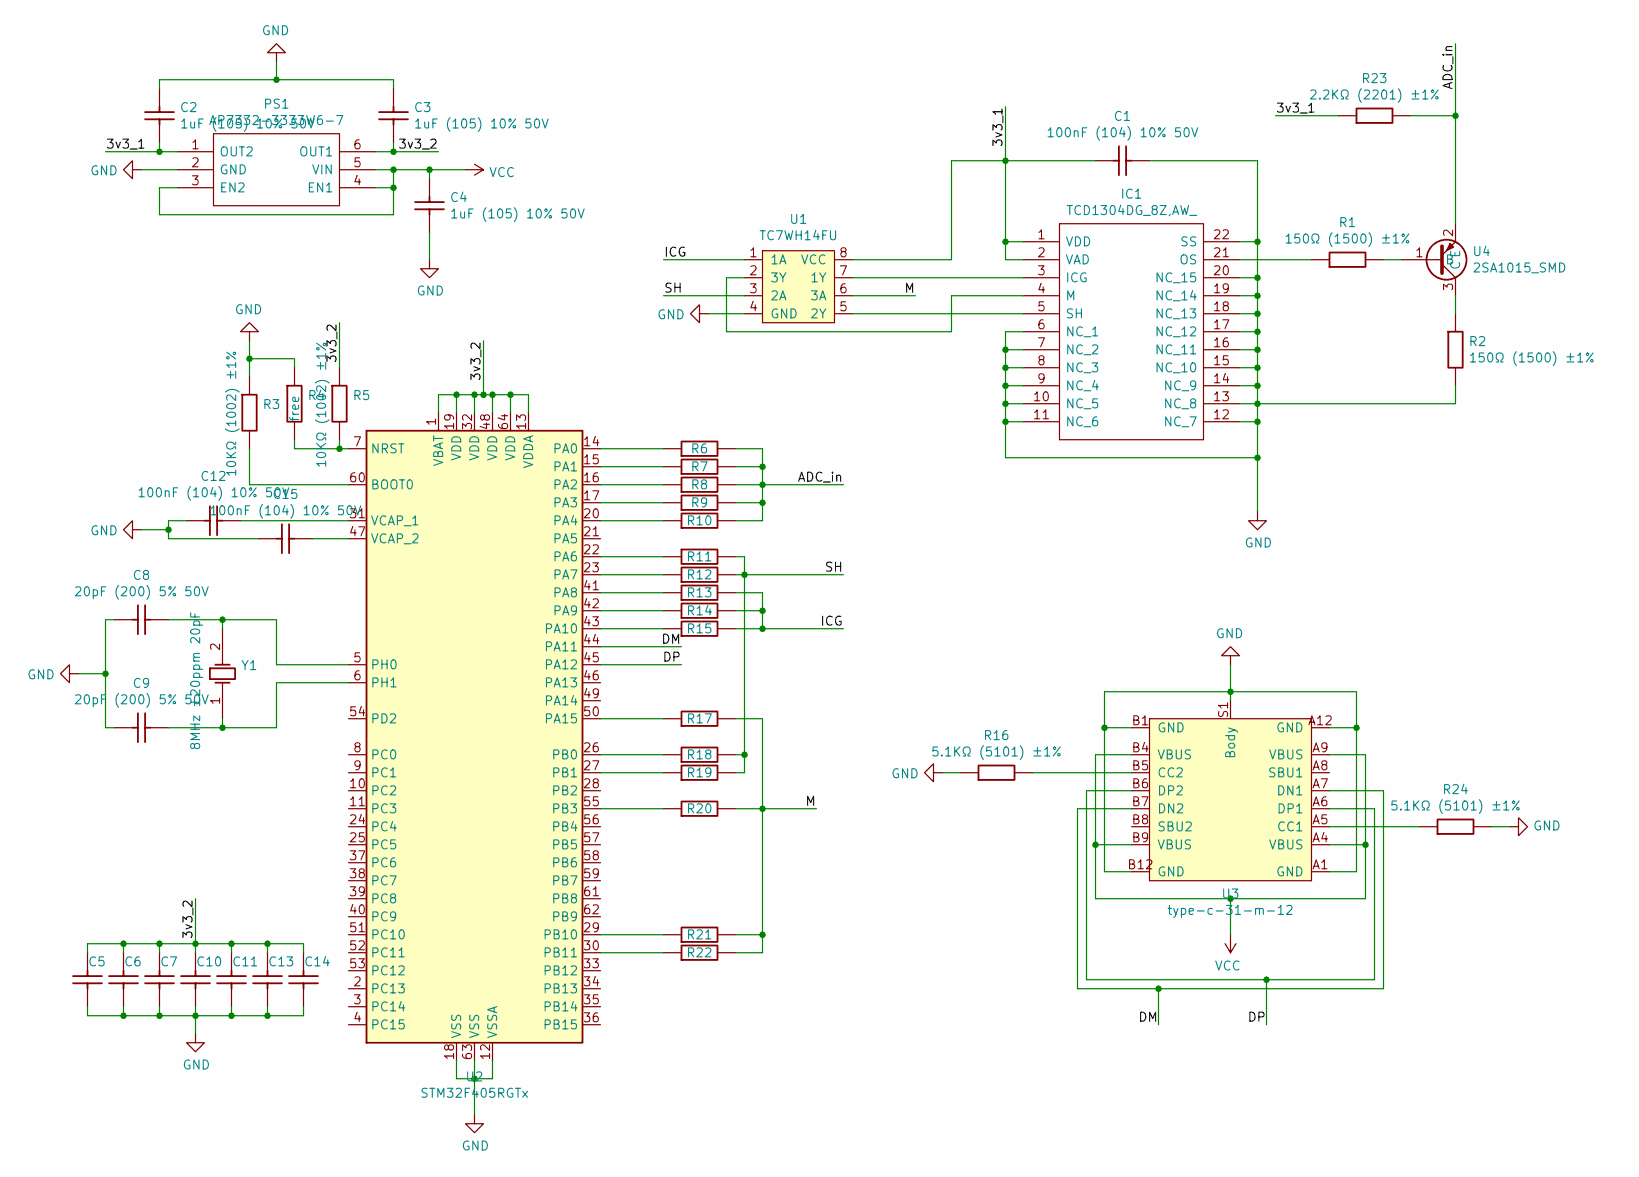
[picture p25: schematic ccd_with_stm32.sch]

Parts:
C1, C5, C6, C7, C10, C11, C12, C13, C15: 0603_100nF__104_10%_50V; 0603_C
C2, C3, C4, C14: 0603_1uF__105_10%_50V; 0603_C
C8, C9: 0603_20pF__200_5%_50V; 0603_C
IC1: TCD1304DG_8Z,AW_; DIP1016W62P254L4160H372Q22N; Manufacturer_Part_Number TCD1304DG(8Z,AW); Mouser Part Number 757-TCD1304DG8ZAW
PS1: AP7332-3333W6-7; SOT95P275X110-6N; Manufacturer_Part_Number AP7332-3333W6-7; Mouser Part Number 621-AP7332-3333W6-7
R1, R2: 0603_150Ω__1500_1%; 0603_R
R3, R5: 0603_10KΩ__1002_1%; 0603_R
R4: 0402_1.2KΩ__1201_1%; 0402_R
R6, R7, R8, R9, R10, R11, R12, R13, R14, R15, R17, R18, R19, R20, R21, R22: 0402_0Ω__0R0_1%; 0402_R
R16, R24: 0603_5.1KΩ__5101_1%; 0603_R
R23: 0603_2.2KΩ__2201_1%; 0603_R
U1: TC7WH14FU; SOP65P640X120-8N
U2: STM32F405RGTx; LQFP-64_10x10mm_P0.5mm
U3: type-c-31-m-12; USB_C_Receptacle_HRO_TYPE-C-31-M-12
U4: 2SA1015_SMD; SOT-23(SOT-23-3)
Y1: SMD-5032_2P_8MHz_20ppm_20pF; SMD-5032_2P

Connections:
/3v3_1: C1.1, C2.2, IC1.1 (VDD), IC1.2 (VAD), PS1.1 (OUT2), R23.1, U1.8 (VCC)
/3v3_2: C3.2, C5.1, C6.1, C7.1, C10.1, C11.1, C13.1, C14.1, PS1.6 (OUT1), R5.1, U2.1 (VBAT), U2.13 (VDDA), U2.19 (VDD), U2.32 (VDD), U2.48 (VDD), U2.64 (VDD)
/ADC_in: R6.2, R7.2, R8.2, R9.2, R10.2, R23.2, U4.2 (E)
/DM: U2.44 (PA11), U3.A7 (DN1), U3.B7 (DN2)
/DP: U2.45 (PA12), U3.A6 (DP1), U3.B6 (DP2)
/ICG: R13.2, R14.2, R15.2, U1.1 (1A)
/M: R17.2, R20.2, R21.2, R22.2, U1.6 (3A)
/SH: R11.2, R12.2, R18.2, R19.2, U1.3 (2A)
GND: C1.2, C2.1, C3.1, C4.2, C5.2, C6.2, C7.2, C8.1, C9.1, C10.2, C11.2, C12.1, C13.2, C14.2, C15.1, IC1.6 (NC_1), IC1.7 (NC_2), IC1.8 (NC_3), IC1.9 (NC_4), IC1.10 (NC_5), IC1.11 (NC_6), IC1.12 (NC_7), IC1.13 (NC_8), IC1.14 (NC_9), IC1.15 (NC_10), IC1.16 (NC_11), IC1.17 (NC_12), IC1.18 (NC_13), IC1.19 (NC_14), IC1.20 (NC_15), IC1.22 (SS), PS1.2 (GND), R2.2, R3.1, R4.1, R16.1, R24.2, U1.4 (GND), U2.12 (VSSA), U2.18 (VSS), U2.63 (VSS), U3.A1 (GND), U3.A12 (GND), U3.B1 (GND), U3.B12 (GND), U3.S1 (Body)
unnamed: C8.2, U2.5 (PH0), Y1.2 (OSC2)
unnamed: C9.2, U2.6 (PH1), Y1.1 (OSC1)
unnamed: C12.2, U2.31 (VCAP_1)
unnamed: C15.2, U2.47 (VCAP_2)
unnamed: IC1.3 (ICG), U1.7 (1Y)
unnamed: IC1.4 (M), U1.2 (3Y)
unnamed: IC1.5 (SH), U1.5 (2Y)
unnamed: IC1.21 (OS), R1.1
unnamed: R1.2, U4.1 (B)
unnamed: R2.1, U4.3 (C)
unnamed: R3.2, U2.60 (BOOT0)
unnamed: R4.2, R5.2, U2.7 (NRST)
unnamed: R6.1, U2.14 (PA0)
unnamed: R7.1, U2.15 (PA1)
unnamed: R8.1, U2.16 (PA2)
unnamed: R9.1, U2.17 (PA3)
unnamed: R10.1, U2.20 (PA4)
unnamed: R11.1, U2.22 (PA6)
unnamed: R12.1, U2.23 (PA7)
unnamed: R13.1, U2.41 (PA8)
unnamed: R14.1, U2.42 (PA9)
unnamed: R15.1, U2.43 (PA10)
unnamed: R16.2, U3.B5 (CC2)
unnamed: R17.1, U2.50 (PA15)
unnamed: R18.1, U2.26 (PB0)
unnamed: R19.1, U2.27 (PB1)
unnamed: R20.1, U2.55 (PB3)
unnamed: R21.1, U2.29 (PB10)
unnamed: R22.1, U2.30 (PB11)
unnamed: R24.1, U3.A5 (CC1)
VCC: C4.1, PS1.3 (EN2), PS1.4 (EN1), PS1.5 (VIN), U3.A4 (VBUS), U3.A9 (VBUS), U3.B4 (VBUS), U3.B9 (VBUS)

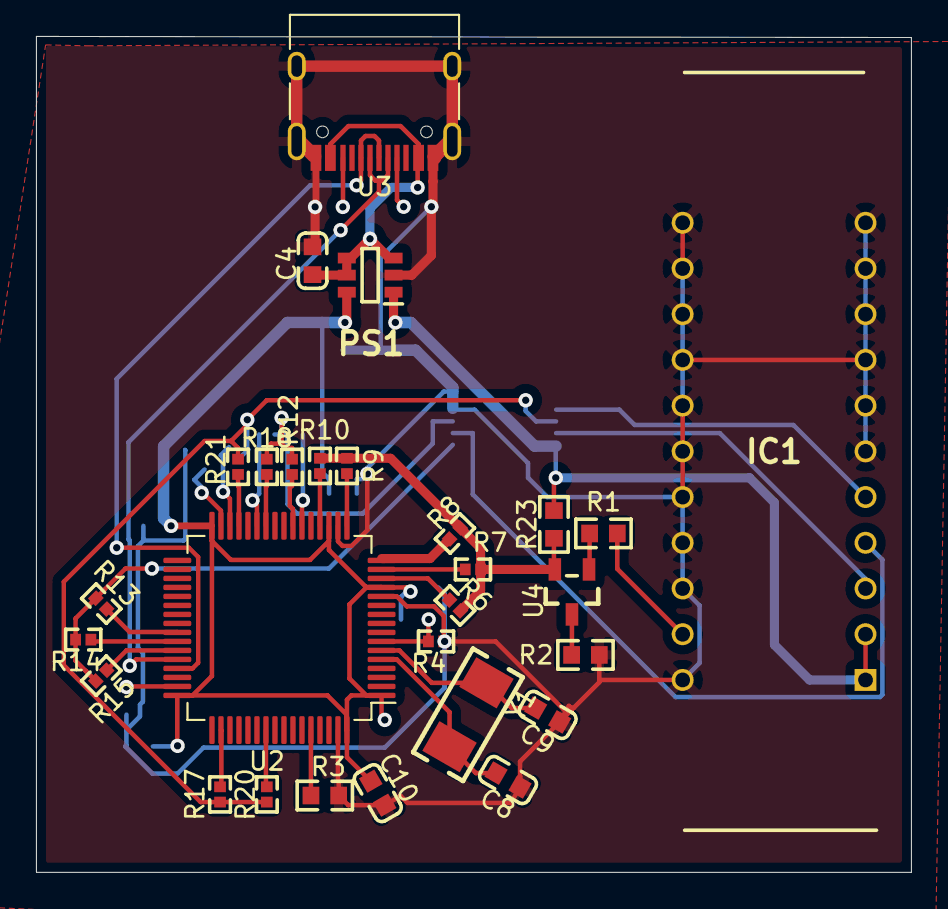
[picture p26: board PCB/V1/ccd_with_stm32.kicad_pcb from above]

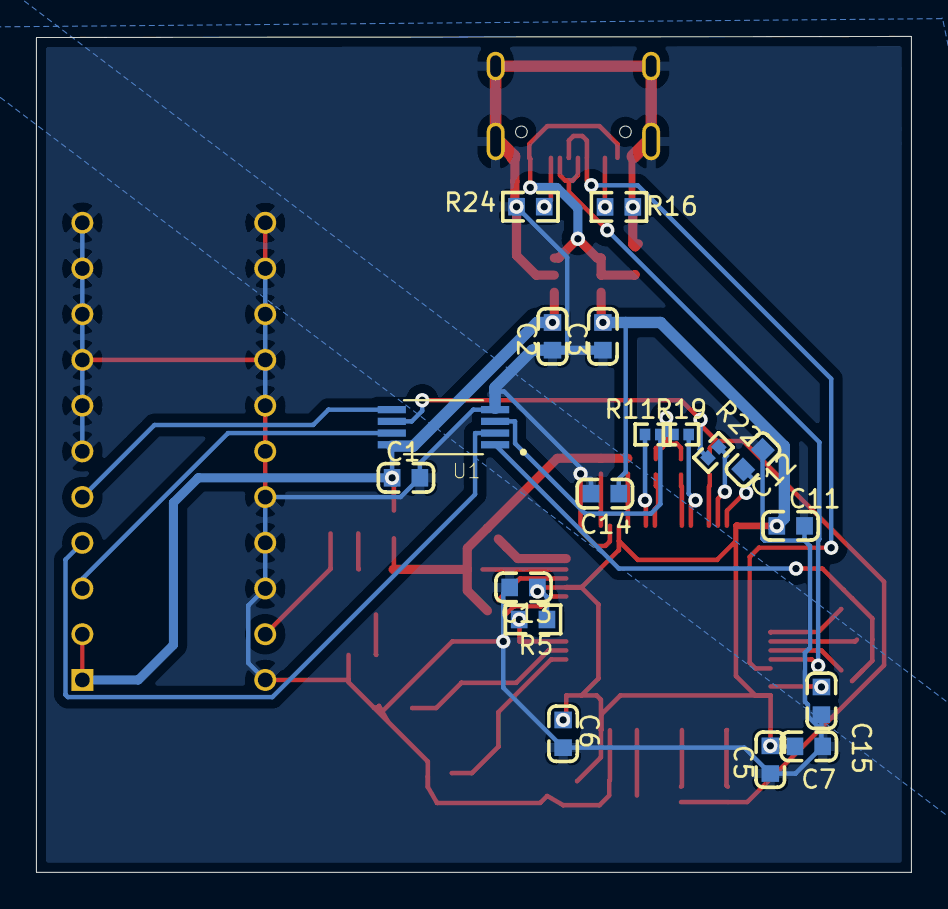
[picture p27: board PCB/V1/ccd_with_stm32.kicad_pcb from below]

Board: 2 copper layers, 48.6 x 46.4 mm, 46 parts (18 on the bottom side), 40 nets.

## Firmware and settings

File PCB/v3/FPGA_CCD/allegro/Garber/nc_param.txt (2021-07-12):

INTEGER-PLACES         5
DECIMAL-PLACES         5
X-OFFSET               0.000000
Y-OFFSET               0.000000
FEEDRATE               1
COORDINATES            ABSOLUTE
OUTPUT-UNITS           ENGLISH
TOOL-ORDER             INCREASING
REPEAT-CODES           YES
SUPPRESS-LEAD-ZEROES   YES
SUPPRESS-TRAIL-ZEROES  NO
SUPPRESS-EQUAL         NO
TOOL-SELECT            YES
OPTIMIZE_DRILLING      YES
ENHANCED_EXCELLON      YES
HEADER                 none
LEADER                 12
CODE                   ASCII
SEPARATE               NO
SEPARATE-ROUTING       NO
DRILLING               LAYER-PAIR
BACKDRILL              NO
CAVITY                 NO
COUNTER                NO
TOLERANCE_DRILL        YES
TOLERANCE_TRAVEL       YES
TOOL_SIZE              YES
ROTATION               YES
NON_STANDARD           YES
TOTAL_DRILL            NO
SEPARATE_SLOT          NO
SUPPRESS_TOLERANCE     YES
SUPPRESS_TOOLSIZE      YES
SUPPRESS_ROTATION      YES

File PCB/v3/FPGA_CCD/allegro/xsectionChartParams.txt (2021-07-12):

CHART_UNIT Mils
LAYER_NAME YES
LAYER_THICKNESS YES
LAYER_THICKNESS_TOL NO
MATERIAL_NAME YES
EMB_STATUS NO
ATTACH_METHOD NO
LAYER_TYPE YES
DRILL_SPAN YES
BACKDRILL_SPAN NO
STACKED_VIAS YES
EMD_COMP_LEGEND  NO
DRILL_LABEL  YES
X_SCALE_FACTOR  1.000
DIELECTRIC_SCALE_FACTOR  1.000
TEXT_BLOCK  1
MAX_CHART_HEIGHT 2000 MIL

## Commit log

2021-05-13 initial commit
    Initial commit. ONLY framework.
2021-05-13 pcb file added
    [ccd_with_stm32-B_Cu.gbr, ccd_with_stm32-B_Mask.gbr, ccd_with_stm32-B_Paste.gbr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]
2021-05-15 pcb v2
    [ccd_with_stm32-B_Cu.gbr, ccd_with_stm32-B_Mask.gbr, ccd_with_stm32-B_Paste.gbr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]
2021-07-12 update pcb & verilog code
    [FPGA_CCD.DSN, HT_Serial_Interface_isim_beh.exe_main.nt64.obj, cases.cfg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]
2021-07-12 update structure
    [Light18.dxf, box.ipt, box.obj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]
2021-07-12 change the name of Structure_Design file director
    [Light18.dxf, box.ipt, box.obj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]
